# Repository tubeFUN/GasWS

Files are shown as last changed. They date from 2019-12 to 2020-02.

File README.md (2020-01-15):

# Project Name
> Gas Warning System (GWS)

## Table of contents
* [General info](#general-info)
* [Screenshots](#screenshots)
* [Technologies](#technologies)
* [Setup](#setup)
* [Features](#features)
* [Status](#status)
* [Inspiration](#inspiration)
* [Parts and footprints list](#Parts-and-footprints-list)
* [Allowed (planned) SMS commands](#Allowed-(planned)-SMS-commands)
* [Principle of operation](#principle-of-operation)
* [Contact](#contact)

## General info
From scratch self-made home alarm system with gas sensor to ensure the safety of residents.
Adaptable system can be modified to gather information from other sensors like flood, carbon monoxide, etc according to residents demends.
System board is powered from the power supply or from battery in case of power failure.
Information about exceed sensor value is send to declared phone number via SMS.

## Screenshots
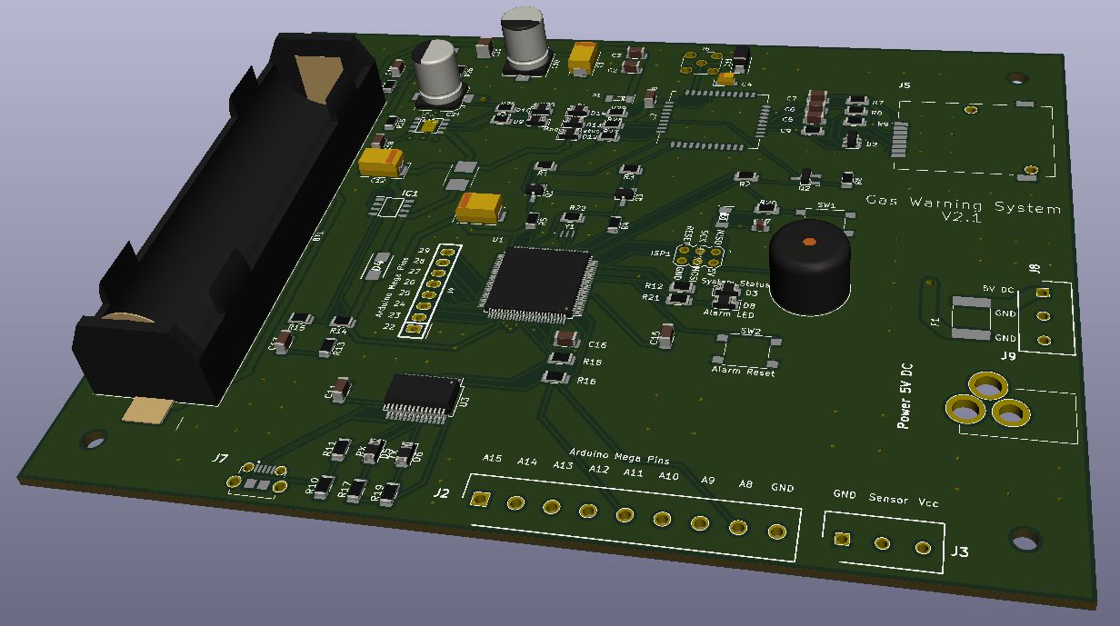
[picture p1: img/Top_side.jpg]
Top side 3D

3D wiew of PCB top side. PCB version 2.1

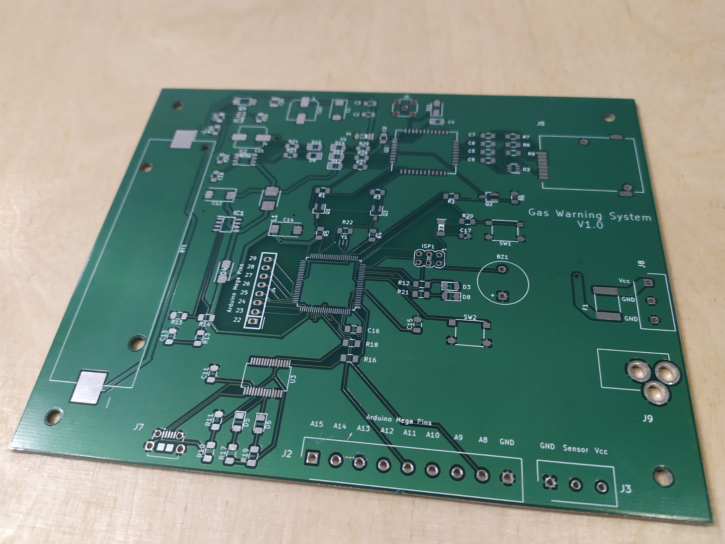
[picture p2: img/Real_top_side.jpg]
Top side real

Real wiew of PCB top side. PCB version 1.0

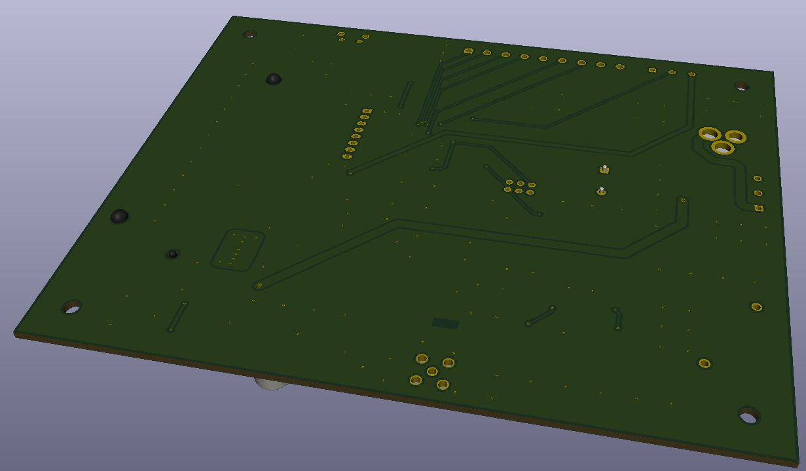
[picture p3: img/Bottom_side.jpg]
Bottom side 3D

3D wiew of PCB bottom side. PCB version 2.1

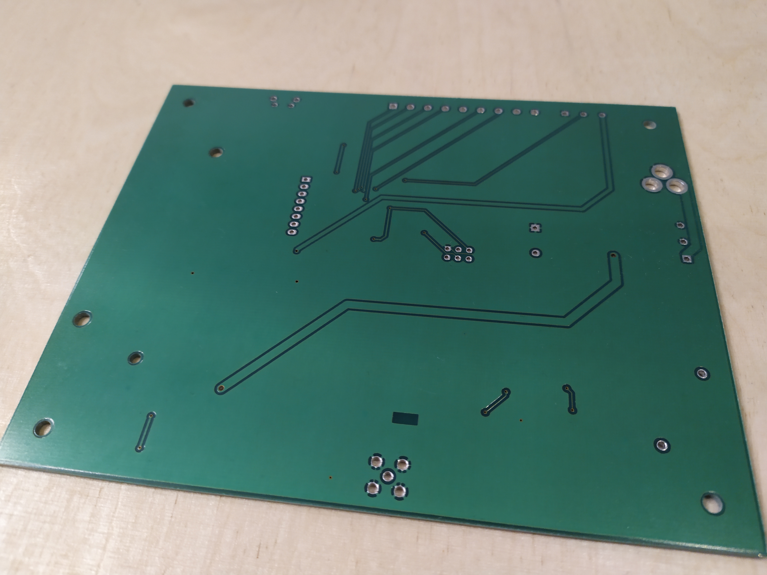
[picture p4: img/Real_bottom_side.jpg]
Bottom side real

Real wiew of PCB bottom side. PCB version 1.0

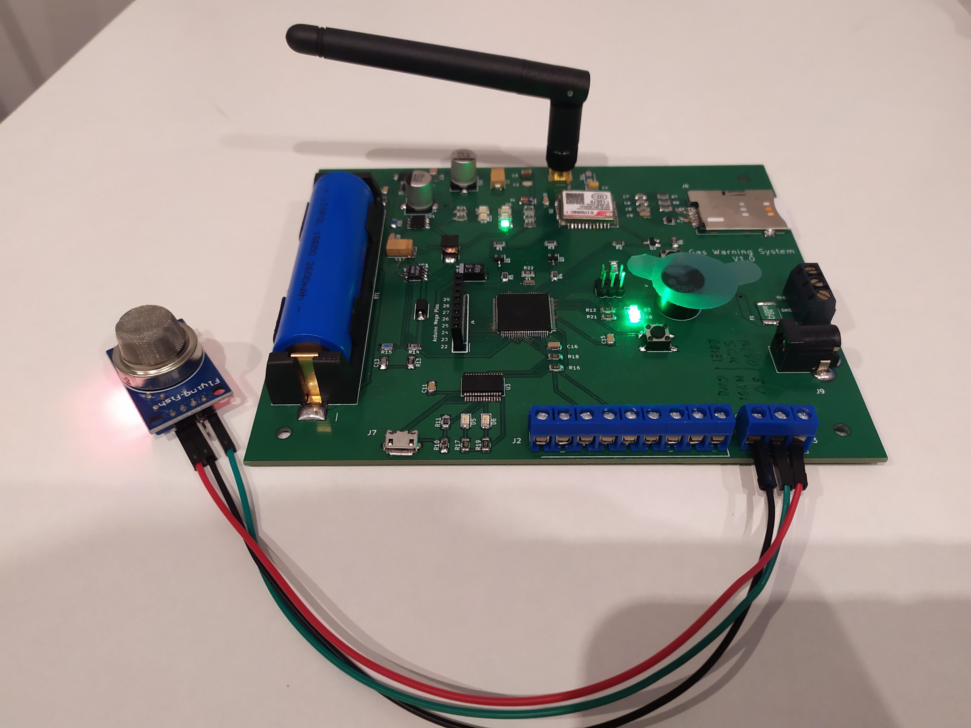
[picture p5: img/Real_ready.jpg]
Bottom side real

View of the ready PCB, version 1.0.

## Technologies
* Arduino 1.8.10 as an IDE
* Arduino Mega 2560 as a testing board
* MQ-2 Gas Sensor
* SIM800C 2G module
* KiCad 5.1.4 as EDA Suite
* freeRouting.jar as an autorouter
* USBASP v2.0 as a target programmer
* AVRdude v6.3

## Setup
In the first step, enter the phone number on line 19 of the Gas_warning_system_v21.ino file to which SMS notifications will be sent. Then prepare the Arduino IDE. To receive long SMS (160 characters) it is needed to extend serials buffer size. To do this in the location:  
"C:\Program Files(x86)\Arduino\hardware\arduino\avr\cores\arduino\HardwareSerial.h  
change buffer size to:  
#define SERIAL_TX_BUFFER_SIZE 254  
#define SERIAL_RX_BUFFER_SIZE 254  

In the next step, you need to compile the code in the Arduino IDE and export it to the .hex format, use the keyboard shortcut Ctrl + Alt + S. The imported files will appear in the folder in which we placed the Gas_warning_system_v21.ino file. We are interested in the Gas_warning_system_v21.ino.mega.hex file, which does not contain a bootloader. This file is uploaded to the microcontroller using the ISP programmer. I use USBAsp in combination with avrdude. If you prefer to use the "windows", I recommend the avrdude graphic overlay called AVRDUDESS 2.11. The Arduino IDE also allows programming of microcontrollers using an external programmer (USBasp), by the way, it uses avrdude. 
Finally, set the fusebits.  

Default ATmega2560 fuses & lock bits:  
L 0x62  
H 0x99  
E 0xFF  
LB 0x3F  

GWS ATmega2560 fuses & lock bits:  
L 0xFF  
H 0xD8  
E 0xFC  
LB 0x3F  
and you can enjoy a working alarm control system.

## Code Examples
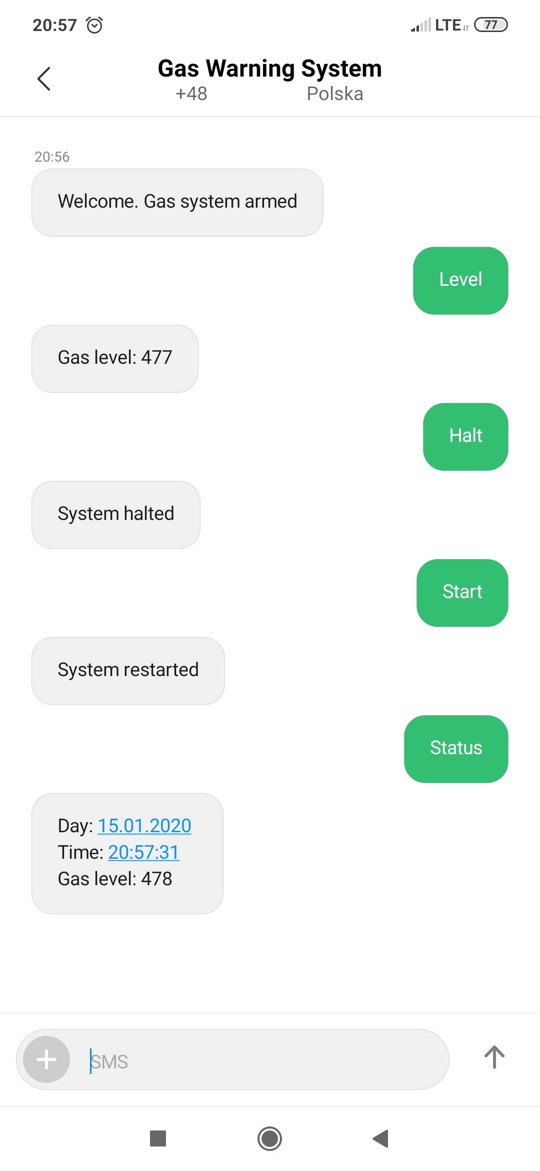
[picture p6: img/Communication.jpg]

Screenshot of SMS communication with GWS.

## Features
List of features ready and TODOs for future development
* Adaptable system, 16 additional GPIO ports for future use
* All modules (uC, converters, GSM modem, buffer power supply with battery) on one PCB
* Battery powered system as a backup with protection circuit
* System monitoring by LED indicators and via USB (virtual COM in OS, adjustable baud rate)
* Alarming by SMS, sound (buzzer) and visually
* Reset switch
* In system programming by USBASP 

To-do list:
* Adding USSD code support
* Improving the readability of the code
* Check the program's resistance to incorrectly entered data
* Adding more sensors and appropriate code

## Status
Project is done.

## Inspiration
Project is based on... my need and to refresh my abilities.

## Parts and footprints list
Parts used to build Gas Warning System

## Allowed SMS commands to Gas Warning System
* Halt - Stops the system
* Start - Starts the system
* Level - Sends an SMS with the current gas level
* Status - Sends an SMS with with the current date, time and gas level
* Account - Account balance (to do)

## Principle of operation
Board schematic

PCB consists of five functional blocks, two DC/DC converters, GSM modem, USB to UART interface, microcontroller with peripherals.
First DC/DC converter (charger) based on TP4056 chip converts 5V DC from the power supply to voltage required by single cell Li-Ion battery (18650 type 2600mAh). The charge voltage is set to 4.2V and the charge current is set by R25 resistor to 1000 mA value. Chip automaticaly terminates the charge cycle when the charge current drops to 1/10th programed value after final float voltage is reached. Batttery is protected from over-discharge and overcharge by DW01A chip. Over-discharge protection - keeps battery from being discharged below 2.4V. Module will cut output power from the battery until the battery voltage has been re-charged above 3.0V. During battery charging TP4056 chip may produce a lot of heat. To dissipate heat a few vias ond copper layer were placed under chip body.

Second converter based on LT1308 is a step-up DC/DC converter. It was design to converts voltage from single Li-Ion to 5V 1A. In Gas Warning System board this voltage is used by USB to UART interface and microcontroller with peripherals blocks.

USB to UART interface is based on well known FT232 chip. It interfaces between USB and Atmega2560 uC UART. In the Windows 10 operating system board is recognised as virtual port (COMx). Driver is installed automaticaly. This feature allows to comunicate with uC from Arduino IDE and monitor Gas Warning System status.

GSM block is based on SIM800C modem. Communication with uC is realized by UART1 (build in the module). AT commands had been succesfully used. Bidirectional logic level conversion was needed to satisfy chips needs. BSS138 transistors had been used to translate between 5V and 4,2V levels. SIM800C is 2G (GSM) generation and uses 900MHz frequency (used in Poland). Three other bands are supported (850, 1800, 1900 MHz) by this module. Transient overvoltage protection has been used to protect ESD component (SIM800C) in signal lines from SIM card.

ATmega2560 is the heart of the system. The same uC is used in Arduino Mega board. uC block is equipped with LEDs, tact switches, buzzer and of course connectors to communicate with sensors like MQ-2 Gas Sensor. Peripherals help user to indicate actual state of the system, do some simple actions or react to alarm. Chip programing is possible via ISP method.

Transistors Q1 and Q3 with neighboring elements perform level conversion between UART (5V) and SIM800C modem (4V). The Q2 circuit is used to enable the SIM800C modem.

## Contact
vacuum.tube.fun@gmail.com

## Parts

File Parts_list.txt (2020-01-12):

Reference	 Value	 Footprint
U2	SIM800C	RF_GSM:SIMCom_SIM800C
R3	10k	Resistor_SMD:R_1206_3216Metric
R4	10k	Resistor_SMD:R_1206_3216Metric
R5	10k	Resistor_SMD:R_1206_3216Metric
R1	10k	Resistor_SMD:R_1206_3216Metric
C1	470uF Tantal ESR	Capacitor_Tantalum_SMD:CP_EIA-7343-31_Kemet-D
C3	33pF	Capacitor_SMD:C_1206_3216Metric
C2	1uF	Capacitor_SMD:C_1206_3216Metric
D1	5V1	smd-semi:SOD-80
C8	100nF	Capacitor_SMD:C_1206_3216Metric
C10	470uF ESR	Capacitor_SMD:CP_Elec_8x10.5
Q2	BC847	Package_TO_SOT_SMD:SOT-23_Handsoldering
R6	47k	Resistor_SMD:R_1206_3216Metric
R2	4,7k	Resistor_SMD:R_1206_3216Metric
C4	4,7u	Capacitor_Tantalum_SMD:CP_EIA-3216-18_Kemet-A
Q3	BSS138	Package_TO_SOT_SMD:SOT-23_Handsoldering
Q1	BSS138	Package_TO_SOT_SMD:SOT-23_Handsoldering
R9	51R	Resistor_SMD:R_1206_3216Metric
R8	51R	Resistor_SMD:R_1206_3216Metric
R7	51R	Resistor_SMD:R_1206_3216Metric
C5	22p	Capacitor_SMD:C_1206_3216Metric
C7	22p	Capacitor_SMD:C_1206_3216Metric
C9	100nF	Resistor_SMD:R_1206_3216Metric
D2	ESD	Package_TO_SOT_SMD:SOT-23-6
C6	22p	Capacitor_SMD:C_1206_3216Metric
R28	1k	Resistor_SMD:R_1206_3216Metric
R27	1k	Resistor_SMD:R_1206_3216Metric
D12	Modem Status	Diode_SMD:D_1206_3216Metric
D13	NET	Diode_SMD:D_1206_3216Metric
R29	1k	Resistor_SMD:R_1206_3216Metric
D14	RF	Diode_SMD:D_1206_3216Metric
J6	Conn_Coaxial	Connector_Coaxial:SMA_Amphenol_132134_Vertical
D11	LXES	Diode_SMD:D_SMA
Y1	CSTCE16M0V53-R0	CSTCE16M0V53-R0:OSC_CSTCE16M0V53-R0
R22	1M	Resistor_SMD:R_1206_3216Metric
C15	100nF	Capacitor_SMD:C_1206_3216Metric
J4	Digital	conn-100mil:CONN-100MIL-F-1x8
ISP1	AVRISP	AVRISP:AVRISP
IC2	TP4056	TP4056:SOP-8
IC3	DW01A-G	DW01A-G:SOT95P190X145-6N
Q4	FS8205A	FS8205A:SOP65P640X120-8N
R24	1k	Resistor_SMD:R_1206_3216Metric
R23	1k	Resistor_SMD:R_1206_3216Metric
D9	PWR	Diode_SMD:D_1206_3216Metric
D10	CHRG	Diode_SMD:D_1206_3216Metric
C18	100nF	Capacitor_SMD:C_1206_3216Metric
C19	100nF	Capacitor_SMD:C_1206_3216Metric
R30	100R	Resistor_SMD:R_1206_3216Metric
R26	1k	Resistor_SMD:R_1206_3216Metric
R25	1.2k	Resistor_SMD:R_1206_3216Metric
BT1	Battery_Cell	Battery:BatteryHolder_Keystone_1042_1x18650
C20	47uF	Capacitor_SMD:C_1210_3225Metric
IC1	LT1308	LT1308ACS8#PBF:SOIC127P599X175-8N
L1	4,7uH	LQH55DN4R7M03L:LQH55DN100M03L
R15	100k	Resistor_SMD:R_1206_3216Metric
R14	309k	Resistor_SMD:R_1206_3216Metric
R13	47k	Resistor_SMD:R_1206_3216Metric
C13	100p	Capacitor_SMD:C_1206_3216Metric
C14	100uF	Capacitor_Tantalum_SMD:CP_EIA-7343-31_Kemet-D
C12	470uF	Capacitor_Tantalum_SMD:CP_EIA-7343-31_Kemet-D
R18	1k	Resistor_SMD:R_1206_3216Metric
R16	1k	Resistor_SMD:R_1206_3216Metric
R19	1k	Resistor_SMD:R_1206_3216Metric
R17	1k	Resistor_SMD:R_1206_3216Metric
D6	TX	Diode_SMD:D_1206_3216Metric
D5	RX	Diode_SMD:D_1206_3216Metric
R10	4,7k	Resistor_SMD:R_1206_3216Metric
R11	10k	Resistor_SMD:R_1206_3216Metric
C11	100nF	Capacitor_SMD:C_1206_3216Metric
BZ1	Buzzer	Buzzer_Beeper:Buzzer_12x9.5RM7.6
SW2	Alarm Reset	Button_Switch_SMD:SW_Push_1P1T_NO_6x6mm_H9.5mm
R21	1k	Resistor_SMD:R_1206_3216Metric
D8	System Status	Diode_SMD:D_1206_3216Metric
R12	1k	Resistor_SMD:R_1206_3216Metric
D3	Alarm LED	Diode_SMD:D_1206_3216Metric
J3	Gas Sensor	CTB5202_3:SHDR3W100P0X500_1X3_1500X760X1020P
C16	100nF	Capacitor_SMD:C_1206_3216Metric
F1	2A	Fuse:Fuse_2920_7451Metric
U3	FT232RL	Package_SO:SSOP-28_5.3x10.2mm_P0.65mm
J2	282836-9	282836-9:SHDR9W130P0X500_1X9_4500X820X1020P
J9	Power 5V DC	CON-SOCJ-2155:CONSOCJ2155
J8	Power	CTB5202_3:SHDR3W100P0X500_1X3_1500X760X1020P
J7	USB	10118194-0011LF:101181940011LF
C21	470uF ESR	Capacitor_SMD:CP_Elec_8x10.5
D4	VS-10BQ015-M3_5BT	VS-10BQ015-M3_5BT:DIOM5436X244N
C17	22p	Capacitor_SMD:C_0805_2012Metric
R20	10k	Resistor_SMD:R_1206_3216Metric
D7	LL4148	smd-semi:SOD-80
SW1	SW_DIP_x01	Button_Switch_SMD:SW_Push_1P1T_NO_6x6mm_H9.5mm
U1	ATmega2560-16AU	Package_QFP:TQFP-100_14x14mm_P0.5mm
J5	SIM	47553-1001:475531001

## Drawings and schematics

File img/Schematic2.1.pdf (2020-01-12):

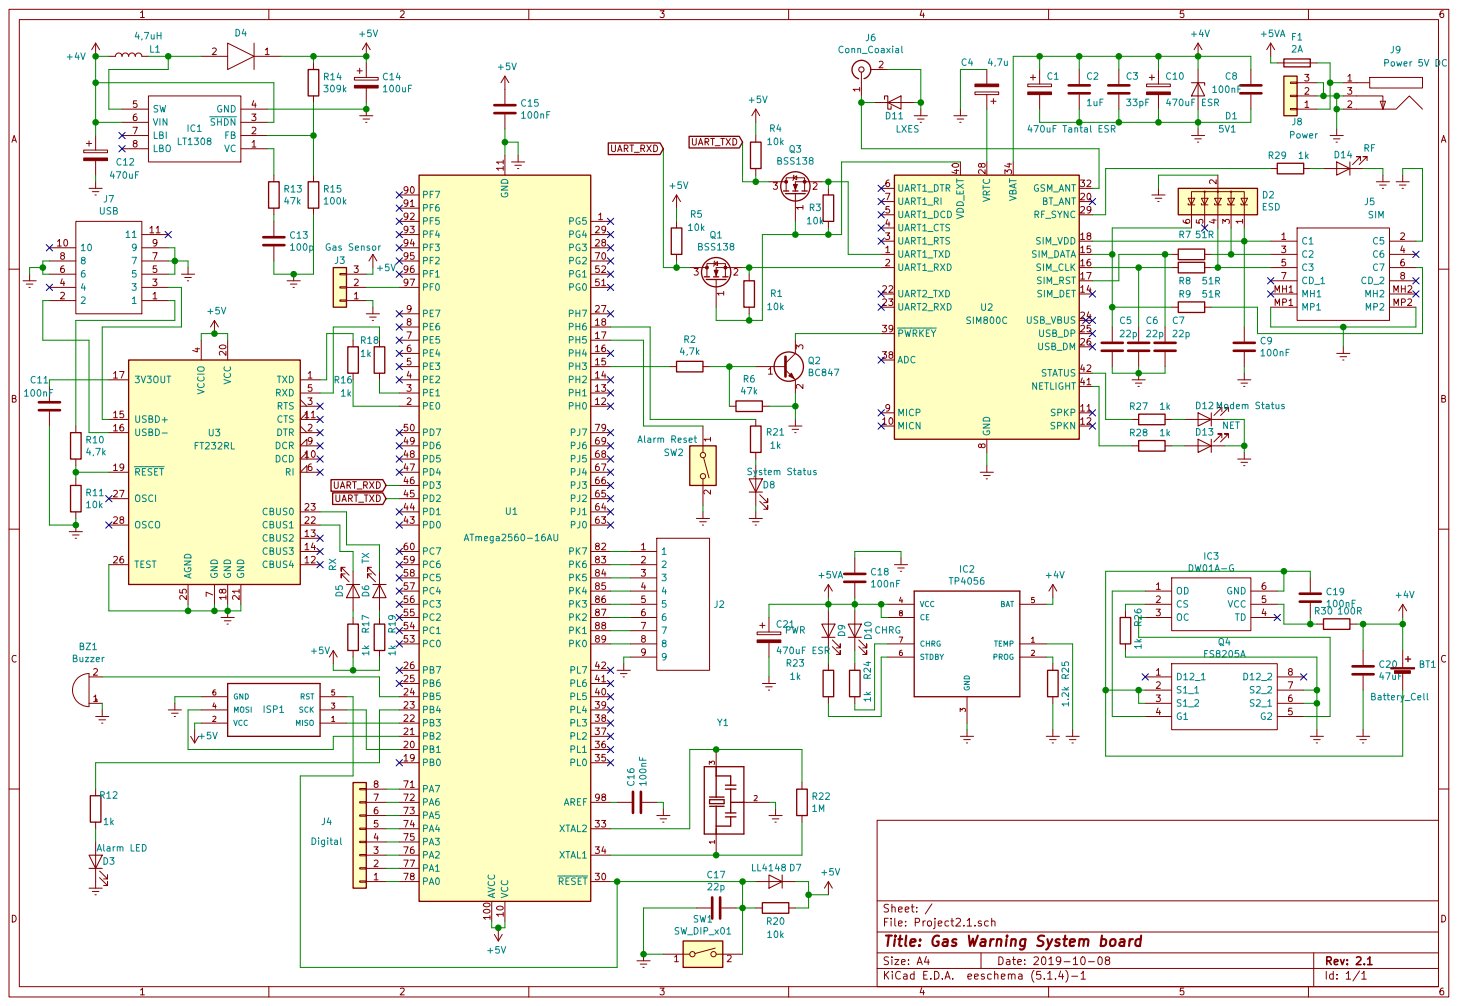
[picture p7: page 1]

3 VCC 4 BAT 5 STDBY 6 CHRG 7 CE 8

File: Project2.1.sch Sheet: /
Id: 1/1 Title: Gas Warning System board

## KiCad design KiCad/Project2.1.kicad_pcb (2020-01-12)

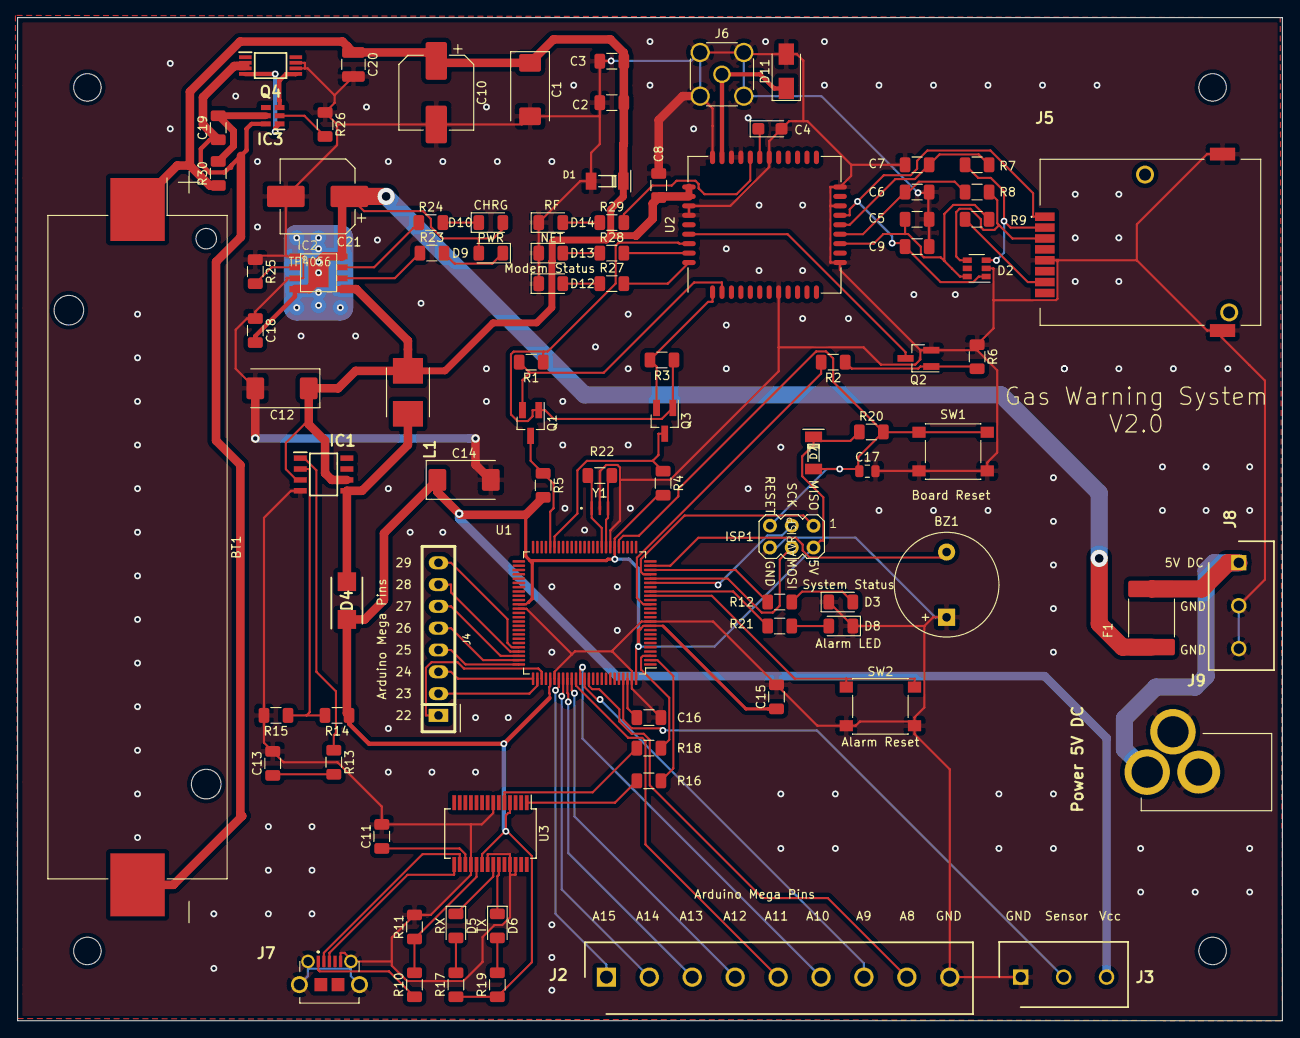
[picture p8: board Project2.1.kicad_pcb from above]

Board: 2 copper layers, 147.3 x 116.8 mm, 91 parts (0 on the bottom side), 85 nets.

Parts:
BT1: Battery_Cell; BatteryHolder_Keystone_1042_1x18650
BZ1: Buzzer; Buzzer_12x9.5RM7.6
C1: 100uF Tantal ESR; CP_EIA-7343-31_Kemet-D
C2: 1uF; C_1206_3216Metric
C3: 33pF; C_1206_3216Metric
C4: 4,7u; CP_EIA-3216-18_Kemet-A
C5, C6, C7: 22p; C_1206_3216Metric
C8, C11, C15, C16, C18, C19: 100nF; C_1206_3216Metric
C9: 100nF; R_1206_3216Metric
C10, C21: 470uF ESR; CP_Elec_8x10.5
C12: 47uF; CP_EIA-7343-31_Kemet-D
C13: 100p; C_1206_3216Metric
C14: 100uF; CP_EIA-7343-31_Kemet-D
C17: 22p; C_0805_2012Metric
C20: 47uF; C_1210_3225Metric
D1: 5V1; SOD-80
D2: ESD; SOT-23-6
D3: Alarm LED; D_1206_3216Metric
D4: VS-10BQ015-M3_5BT; DIOM5436X244N
D5: RX; D_1206_3216Metric
D6: TX; D_1206_3216Metric
D7: LL4148; SOD-80
D8: System Status; D_1206_3216Metric
D9: PWR; D_1206_3216Metric
D10: CHRG; D_1206_3216Metric
D11: LXES; D_SMA
D12: Modem Status; D_1206_3216Metric
D13: NET; D_1206_3216Metric
D14: RF; D_1206_3216Metric
F1: 2A; Fuse_2920_7451Metric
IC1: LT1308; SOIC127P599X175-8N
IC2: TP4056; SOP-8
IC3: DW01A-G; SOT95P190X145-6N
ISP1: AVRISP
J2: 282836-9; SHDR9W130P0X500_1X9_4500X820X1020P
J3: Gas Sensor; SHDR3W100P0X500_1X3_1500X760X1020P
J4: Digital; CONN-100MIL-F-1x8
J5: SIM; 475531001
J6: Conn_Coaxial; SMA_Amphenol_132134_Vertical
J7: USB; 101181940011LF
J8: Power; SHDR3W100P0X500_1X3_1500X760X1020P
J9: Power 5V DC; CONSOCJ2155
L1: 4,7uH; LQH55DN100M03L
Q1, Q3: BSS138; SOT-23_Handsoldering
Q2: BC847; SOT-23_Handsoldering
Q4: FS8205A; SOP65P640X120-8N
R1, R3, R4, R5, R11, R20: 10k; R_1206_3216Metric
R2, R10: 4,7k; R_1206_3216Metric
R6, R13: 47k; R_1206_3216Metric
R7, R8, R9: 51R; R_1206_3216Metric
R12, R16, R17, R18, R19, R21, R23, R24, R25, R26, R27, R28, R29: 1k; R_1206_3216Metric
R14: 309k; R_1206_3216Metric
R15: 100k; R_1206_3216Metric
R22: 1M; R_1206_3216Metric
R30: 100R; R_1206_3216Metric
SW1: SW_DIP_x01; SW_Push_1P1T_NO_6x6mm_H9.5mm
SW2: Alarm Reset; SW_Push_1P1T_NO_6x6mm_H9.5mm
U1: ATmega2560-16AU; TQFP-100_14x14mm_P0.5mm
U2: SIM800C; SIMCom_SIM800C
U3: FT232RL; SSOP-28_5.3x10.2mm_P0.65mm
Y1: CSTCE16M0V53-R0; OSC_CSTCE16M0V53-R0

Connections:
+4V: BT1.1, C1.1, C2.1, C3.1, C8.1, C10.1, C12.1, C20.1, D1.1, IC1.3, IC1.6, IC2.5, L1.1, R30.1, U2.34, U2.35
+5V: C14.1, C15.1, D4.1, D7.1, ISP1.2, J3.3, R4.2, R5.2, R14.1, R17.1, R19.1, R20.1, U1.10, U1.31, U1.61, U1.80, U1.100, U3.4, U3.20
+5VA: C18.2, C21.1, D9.2, D10.2, F1.2, IC2.4, IC2.8
Earth: BZ1.1, C1.2, C2.2, C3.2, C4.2, C5.2, C6.2, C7.2, C8.2, C9.2, C10.2, C11.2, C12.2, C13.2, C14.2, C15.2, C16.2, C17.2, C18.1, C20.2, C21.2, D1.2, D2.2, D3.1, D8.1, D11.2, D12.1, D13.1, D14.1, IC1.4, IC2.1, IC2.3, ISP1.6, J2.9, J3.1, J5.5, J5.MP1, J5.MP2, J6.2, J7.5, J7.6, J7.7, J7.8, J7.9, J8.2, J8.3, J9.2, J9.3, Q2.2, Q4.6, Q4.7, R6.1, R11.2, R15.2, R25.1, R26.1, SW1.1, SW2.2, U1.11, U1.32, U1.62, U1.81, U1.99, U2.8, U2.13, U2.19, U2.21, U2.27, U2.30, U2.31, U2.33, U2.36, U2.37, U3.7, U3.18, U3.21, U3.25, U3.26, Y1.2
unnamed: BT1.2, C19.1, IC3.6, Q4.2, Q4.3
unnamed: BZ1.2, U1.24
unnamed: C4.1, U2.28
unnamed: C5.1, D2.6, R9.2, U2.15
unnamed: C6.1, R8.2, U2.16
unnamed: C7.1, R7.2, U2.17
unnamed: C9.1, D2.1, J5.1, U2.18
unnamed: C11.1, U3.17
unnamed: C13.1, R13.2
unnamed: C16.1, U1.98
unnamed: C17.1, D7.2, ISP1.5, R20.2, SW1.2, U1.30
unnamed: C19.2, IC3.5, R30.2
unnamed: D2.3, J5.2, R7.1
unnamed: D2.4, J5.3, R8.1
unnamed: D3.2, R12.1
unnamed: D4.2, IC1.5, L1.2
unnamed: D5.1, U3.22
unnamed: D5.2, R17.2
unnamed: D6.1, U3.23
unnamed: D6.2, R19.2
unnamed: D8.2, R21.1
unnamed: D9.1, R23.2
unnamed: D10.1, R24.2
unnamed: D11.1, J6.1, U2.32
unnamed: D12.2, R27.1
unnamed: D13.2, R28.1
unnamed: D14.2, R29.1
unnamed: F1.1, J8.1, J9.1
unnamed: IC1.1, R13.1
unnamed: IC1.2, R14.2, R15.1
unnamed: IC2.2, R25.2
unnamed: IC2.6, R23.1
unnamed: IC2.7, R24.1
unnamed: IC3.1, Q4.4
unnamed: IC3.2, R26.2
unnamed: IC3.3, Q4.5
unnamed: ISP1.1, U1.22
unnamed: ISP1.3, U1.20
unnamed: ISP1.4, U1.21
unnamed: J2.1, U1.82
unnamed: J2.2, U1.83
unnamed: J2.3, U1.84
unnamed: J2.4, U1.85
unnamed: J2.5, U1.86
unnamed: J2.6, U1.87
unnamed: J2.7, U1.88
unnamed: J2.8, U1.89
unnamed: J3.2, U1.97
unnamed: J4.1, U1.78
unnamed: J4.2, U1.77
unnamed: J4.3, U1.76
unnamed: J4.4, U1.75
unnamed: J4.5, U1.74
unnamed: J4.6, U1.73
unnamed: J4.7, U1.72
unnamed: J4.8, U1.71
unnamed: J5.7, R9.1
unnamed: J7.1, R10.1
unnamed: J7.2, U3.16
unnamed: J7.3, U3.15
unnamed: Q1.1, Q3.1, R1.1, R3.1, U2.40
unnamed: Q1.2, R1.2, U2.2
unnamed: Q2.1, R2.1, R6.2
unnamed: Q2.3, U2.39
unnamed: Q3.2, R3.2, U2.1
unnamed: R2.2, U1.15
unnamed: R10.2, R11.1, U3.19
unnamed: R12.2, U1.23
unnamed: R16.1, U3.1
unnamed: R16.2, U1.2
unnamed: R18.1, U3.5
unnamed: R18.2, U1.3
unnamed: R21.2, U1.18
unnamed: R22.1, U1.33, Y1.3
unnamed: R22.2, U1.34, Y1.1
unnamed: R27.2, U2.42
unnamed: R28.2, U2.41
unnamed: R29.2, U2.29
unnamed: SW2.1, U1.17
UART_RXD: Q1.3, R5.1, U1.46
UART_TXD: Q3.3, R4.1, U1.45

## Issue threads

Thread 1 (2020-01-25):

SIM800C module stops registering in the network

tubeFUN, 2020-01-25:
I noticed that the system is working properly for several days, after which the SIM800C modem loses connection to the GSM network and does not try to register in the network again. A similar case is described here:
https://www.electro-tech-online.com/threads/sim800-module-stops-registering-after-a-few-days.149029/
A temporary solution is to add a function to the program to check the status of the GSM network connection and restart the modem in case of connection loss.
The changes will be reflected in the Gas_warning_system_v22.ino file.

Closed 2020-01-26.

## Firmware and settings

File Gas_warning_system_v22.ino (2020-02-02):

/*
 * Gas Warning System
 * https://github.com/tubeFUN/GasWS/blob/master/README.md
 */

  
#define pin_red_LED 10 //Pin 18 ATmega2560 "Alarm LED"
#define pin_green_LED 9 //Pin 23 ATmega2560 "Status LED"
#define pin_gas_sensor A0 //Pin 97 ATmega2560 "Gas sensor - analog input"
#define pin_buzzer 11 //Pin 24 ATmega2560 "Buzzer"
#define pin_switch 8 //Pin 17 ATmega2560 "Alarm reset"
#define pin_SIM800_power 6 //Pin 15 ATmega2560 "SIM800C PWRKEY neg"


int j = 0; //Auxiliary variable
byte m = 0; //Auxiliary variable
int gas_threshold = 700; //Set gas threshold (min 0 - max 1023)
volatile int alarm_state = 1;
int sensor_value = 0; //Gas sensor value
char destination_number1[] = "000000000"; //9-digits format destination number
char destination_number2[] = "*124*#"; //USSD code (ORANGE, POLAND)
char message1[] = "Welcome. Gas Warning System armed."; //Message sent after initialization
char message2[] = "Alarm - gas level exceed! Do something!"; // Message sent after exceeding the gas set threshold
char message4[] = "Level"; //Message read out - Current gas level
char message5[] = "Halt"; //Message read out - System halt
char message6[] = "Start"; //Message read out - System start
char message8[] = "System halted"; //Message sent after system halting
char message9[] = "System restarted"; //Message sent after system restating
char message10[] = "Status"; //Message read out - Current date, time and gas leve
char message11[] = "Account"; //Message read out - Account balance
char date_AT[11]; //Date read from GSM network
char time_AT[9]; //Time read from GSM network
char readed_SMS[260]; //Readed SMS
char CREG_message[30]; //Array to gather CREG message from the network
char CCLK_message[60]; //Array to gather CCLK message from the network
char CNMI_message[360]; //Array to gather CNMI message from the network


void setup() 
{
  pinMode(pin_red_LED, OUTPUT);
  pinMode(pin_green_LED, OUTPUT);
  pinMode(pin_gas_sensor, INPUT);
  pinMode(pin_buzzer, OUTPUT);
  pinMode(pin_switch, INPUT_PULLUP);
  pinMode (pin_SIM800_power, OUTPUT);

  digitalWrite(pin_red_LED, 0);
  digitalWrite(pin_green_LED, 1);
  digitalWrite(pin_buzzer, 0);
  digitalWrite(pin_SIM800_power, 1);  //Power up SIM800C module procedure
  delay(2000); 
  digitalWrite(pin_SIM800_power, 0); 
  delay(1200); 
  digitalWrite(pin_SIM800_power, 1); 
  
  Serial.begin(9600); //Communication with computer
  Serial1.begin(9600); //Communication with GSM modem
   
  Serial.println("Welcome to Gas Warning System serial monitor");
  Serial.println("Network connecting and warming sensor up...");

  Serial.print("Buffer size: ");
  Serial.println(Serial.availableForWrite());//Checking serials buffer size
  Serial.println("Warming sensor up...");
  /*
   * To receive long SMS (160 characters) it is needed to extend serials buffer size.
   * To do this in location:
   * C:\Program Files (x86)\Arduino\hardware\arduino\avr\cores\arduino\HardwareSerial.h
   * change buffer size to:
   * #define SERIAL_TX_BUFFER_SIZE 254
   * #define SERIAL_RX_BUFFER_SIZE 254
   */
   
  delay(60000); //Time required to connect to the network and worming sensor up

  /* 
   *  Initializing and checking GSM modem
   *  To configure network time updating permanently to the modem
   *  it is needed to send AT+CLTS=1;&W
   *  then restart the modem, AT+CFUN=1,1
   */
  
  Serial1.println("AT"); //Check modem status
  while (modem_response() > 0); 
  Serial1.println("AT+IPR=9600"); //Permanently set modem baud rate to 9600
  while (modem_response() > 0);
  Serial1.println("AT+CMGF=1"); // Configuring SMS TEXT mode
  while (modem_response() > 0);
  Serial1.println("AT+CREG?"); //Registration status
  while (modem_response() > 0);
  Serial1.println("AT+COPS?"); //Operator name
  while (modem_response() > 0);
  Serial1.println("AT+CSQ"); //Signal strenght
  while (modem_response() > 0);
  Serial1.println("AT+CNMI=1,2,0,0,0"); // Forwarding SMS directly to the serial
  while (modem_response() > 0);
  Serial1.println("AT+CPMS?"); //Preferred SMS storage.
  while (modem_response() > 0);

  send_SMS(message1); //Send welcome SMS as a sytem test
}


void loop() 
{
  switch(alarm_state)
  {
    //==================================================================
    //State 1 - Waiting
    case 1:    
    Serial.println("State 1 - Waiting");
    digitalWrite(pin_green_LED, 1);
    digitalWrite(pin_red_LED, 0);
    sensor_value = analogRead(pin_gas_sensor);//Read gas value
    delay(2000); //Measure every two second
    Serial.print("Gas value: ");
    Serial.println(sensor_value);

    if (sensor_value > gas_threshold)//Go to stage two after crossing the gas threshold.
      alarm_state = 2;

    if (m == 255)
    {
      if (check_reg_status()) //Modem restart procedure if modem is not registered
      {
        Serial.println("Modem restart");
        digitalWrite(pin_SIM800_power, 0);
        delay(1200); 
        digitalWrite(pin_SIM800_power, 1); 
        delay(2000); 
        digitalWrite(pin_SIM800_power, 0);
        delay(1200);
        digitalWrite(pin_SIM800_power, 1);
        delay(25000); 
      }
    }
    m++;
    
    if (receive_SMS()) //Checking if a new SMS is available
    {
      Serial.println("SMS reading...");
      if (check_message(message5)) //Check incoming SMS for system halt command
      {
        alarm_state = 4;
        send_SMS(message8); //Send SMS informing about system halt
      }
      
      else if (check_message(message10)) //Check incoming SMS for system status command
      {
        get_time(); //Get time from GSM network
        delay(500);
        sensor_value = analogRead(pin_gas_sensor); //Read gas value
        char sensor_value_char[4];
        delay(200);
        char temp_array[80];
        sprintf(sensor_value_char, "%d", sensor_value); //Int to char conversion
        strcpy (temp_array, "Day: ");
        strcat (temp_array, date_AT);
        strcat (temp_array, "\n");
        strcat (temp_array, "Time: ");
        strcat (temp_array, time_AT);
        strcat (temp_array, "\n");
        strcat (temp_array, "Gas level: ");
        strcat (temp_array, sensor_value_char);
        Serial.println(temp_array);
        send_SMS(temp_array); //Send SMS status information
      }

      else if (check_message(message4)) //Check incoming SMS for gas level command
      {
        sensor_value = analogRead(pin_gas_sensor);//Read gas value
        char sensor_value_char[4];
        delay(200);
        char temp_array[20];
        sprintf(sensor_value_char, "%d", sensor_value); //Int to char conversion
        strcpy (temp_array, "Gas level: ");
        strcat (temp_array, sensor_value_char);
        Serial.println(temp_array);
        send_SMS(temp_array); //Send SMS informing about gas level
      }
      
      else if (check_message(message11)) //Check incoming SMS for accound status command
      {
        check_account(destination_number2);//Make call to USSD code
        if (receive_SMS()) //Checking if a new SMS is available
        {
          Serial.println(readed_SMS);
          send_SMS(readed_SMS);
        }
      }
      /*
      else //Send mismatched messages to destination_number1
      {
        Serial.println(readed_SMS);
        send_SMS(readed_SMS);
      }
      */
    }
    break;


    //==================================================================
    //State 2 - Alarming
    case 2:  
    Serial.println("State 2 - Alarming");
    sensor_value = analogRead(pin_gas_sensor);
    Serial.print("Gas value: ");
    Serial.println(sensor_value);
    if (reset_time() == 0)
    {
      digitalWrite(pin_green_LED, 0);
      digitalWrite(pin_red_LED, 1); //Set blinking LED
      digitalWrite(pin_buzzer, 1);
      delay(100);
      digitalWrite(pin_red_LED, 0);     //Set blinking LED
      if (digitalRead(pin_switch) == 0) //Continuous buzzer sound during
        digitalWrite(pin_buzzer, 1);    //button pressed
      else
        digitalWrite(pin_buzzer, 0);
      delay(100);
    }
    else//Go to stage three after reset pushed.
      alarm_state = 3;

    if (j == 0)
    {
      digitalWrite(pin_buzzer, 1);
      send_SMS(message2); //Send SMS informing about gas level exceed
      j++;
    }

    if (receive_SMS())
    {
      Serial.println("SMS reading...");
      if (check_message(message5)) //Check incoming SMS for system halt command
      {
        alarm_state = 4;
        send_SMS(message8); //Send SMS informing about system halt
      }
    }
    break;


    //==================================================================
    //State 3 - Reset
    case 3:  
    Serial.println("State 3 - Reset");
    j = 0;
    alarm_state = 1;
    break;


    //==================================================================
    //State 4 - System halt
    case 4:  
    Serial.println("State 4 - System halt");
    digitalWrite(pin_red_LED, 1);
    digitalWrite(pin_green_LED, 0);
    digitalWrite(pin_buzzer, 0);
    delay(1000);
    
    if (receive_SMS()) //Checking if SMS is available
    {
      Serial.println("SMS reading...");
      if (check_message(message6)) //Check incoming SMS for system start command
      {
        alarm_state = 1;
        send_SMS(message9); //Send SMS informing about system restart
      }
    }
    break;
  }
}



bool receive_SMS()
{
  int k = 0;
  while (Serial1.available() > 0)
  {
    if (k < 359)
    {
      CNMI_message[k] = Serial1.read();
      //Serial.print(CNMI_message[k]);
      k++;
      CNMI_message[k] = '\0'; //Terminate string array
    }
    else
    k++;
  }

  /*
   * Parsing CNMI message to obtain raw SMS.
   * Information about sender number and arrival date and time are discarded.
   */
   
  if (k > 0)
  {
    k = 0; //Looking for begining of raw SMS from CNMI message
    while (!(CNMI_message[k] == '"' && CNMI_message[k + 1] == '\r'))
    {
      k++;
    }
    int i = 0;                             
    while (!(CNMI_message[k + 3] == '\r')) //Looking for end of the SMS 
    {
      readed_SMS[i] = CNMI_message[k + 3];
      k++;
      i++;
    }
    readed_SMS[i] = '\0';
    Serial.print("CNMI Message: ");
    Serial.println(CNMI_message);//CNMI Message
    Serial.print("Readed SMS: ");
    Serial.println(readed_SMS);//Raw SMS
    return 1;
  }
  return 0;
}
 

/*
 * Comparing readed SMS with declared message
 * If SMS is recognized, function returns 1, otherwise it returns 0.
 * For loop searches until it find NULL character in the declared message.
 */
bool check_message(char a[]) 
{
  for (int i=0; a[i] != '\0'; i++)
  {
    if (a[i] != readed_SMS[i])
    {
      return 0;
    }
  }
  return 1;
}


void get_time() //Getting the date and time from the network
{
  Serial1.println("AT+CCLK?");
  delay(1000); //Wait for answer from the network
  int k = 0;
  while(Serial1.available() > 0)
  {
    if (k < 59)
    {
      CCLK_message[k] = Serial1.read();//Saving answer to the array
      k++;
      Serial.print(CCLK_message[k]);
      CCLK_message[k] = '\0'; //Terminate string array
    }
    else
      k++;
  }

  if (k > 0)
  {
    Serial.println(CCLK_message);
    //Serial.print("Current date: ");
    date_AT[0] = CCLK_message[25];
    date_AT[1] = CCLK_message[26];
    date_AT[2] = '.';
    date_AT[3] = CCLK_message[22];
    date_AT[4] = CCLK_message[23];
    date_AT[5] = '.';
    date_AT[6] = '2';
    date_AT[7] = '0';
    date_AT[8] = CCLK_message[19];
    date_AT[9] = CCLK_message[20];
    date_AT[10] = '\0'; // Terminate the array
    //Serial.println(date_AT);
  
    //Serial.print("Current time: ");
    time_AT[0] = CCLK_message[28];
    time_AT[1] = CCLK_message[29];
    time_AT[2] = ':';
    time_AT[3] = CCLK_message[31];
    time_AT[4] = CCLK_message[32];
    time_AT[5] = ':';
    time_AT[6] = CCLK_message[34];
    time_AT[7] = CCLK_message[35];
    time_AT[8] = '\0'; // Terminate the array
    //Serial.println(time_AT);
  }
}


void send_SMS(char a[]) //Sending SMS
{
  Serial1.print("AT+CMGS=\""); //Set destination number
  Serial1.print(destination_number1);
  Serial1.println("\"");
  delay(2000);
  Serial1.print(a); //SMS message to send
  Serial1.write(26); //Special "CTRL-Z" character to send SMS
  delay(5000);
  Serial.println("SMS sent");
  Serial1.println("AT+CMGDA=\"DEL ALL\""); //Delete All SMS
  delay(5000); //Max time required to delete 1 message
}


bool modem_response() //Redirect GSM modem answers to computer Serial
{
  delay(2000);
  while (Serial1.available() > 0)
  {
    Serial.write(Serial1.read());
  }
  return 0;
}


bool reset_time() // Check the reset switch press time. 2 seconds reset the system
{
  int k = 0;
  while (digitalRead(pin_switch) == 0)
  {
    k++;
    delay(200);
    digitalWrite(pin_buzzer, 1);
    Serial.println(k);
    if (k>10) //Waits 2 seconds
    {
      digitalWrite(pin_buzzer, 0);
      return 1;
    }
  }
  digitalWrite(pin_buzzer, 0);
  return 0;
}


void check_account(String code) //Making a call. Sending USSD code
{
  Serial1.print("ATD+ "); //AT command to dial number
  Serial1.print(code); //Number
  Serial1.println(';');//Modifier at the end separates the dial string into multiple dial commands
  delay(10000); //Wait for 10 seconds...
  //mySerial.println("ATH"); //hang up if necessary
}


bool check_reg_status()
{
  Serial1.println("AT+CREG?"); //Checks registration status
  delay(1000);
  int k = 0;
  while(Serial1.available() > 0)
  {
    if (k < 29)
    {
      CREG_message[k] = Serial1.read();//Saving answer to the array
      k++;
      CREG_message[k] = '\0'; //Terminate string array
    }
    else
      k++;
  }

  if (k > 0)
  {
    if (CREG_message[18] == '0' && CREG_message[20] != '1') //Checks two characters of CREG message
      return 1;
  }
  return 0;
}

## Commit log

2019-12-16 RESET net correction
    [Project1.11.kicad_pcb, Project1.11.sch]
2019-12-23 Improve copper fills, antenna treck, add vias, correct RESET track
2019-12-23 Adding real photos of PCB version 1.0
2019-12-28 Version 2.0
    [Project1.1-B_Cu.gbl, Project1.1-B_Mask.gbs, Project1.1-B_SilkS.gbo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]
2020-01-12 Adding Principle of operation
    [Project2.1-B_Cu.gbl, Project2.1-B_Mask.gbs, Project2.1-B_SilkS.gbo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]
2020-01-22 Update Gas_warning_system_v21.ino
    Add power up procedure
